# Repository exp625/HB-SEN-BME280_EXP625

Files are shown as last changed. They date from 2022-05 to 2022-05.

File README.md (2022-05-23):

# HB-SEN-BME280_EXP625

**PCB for DIY AsksinPP++ Temperature/Humidity/Pressure sensor based on a BOSCH BME280 sensor and an Arduino Pro Mini**

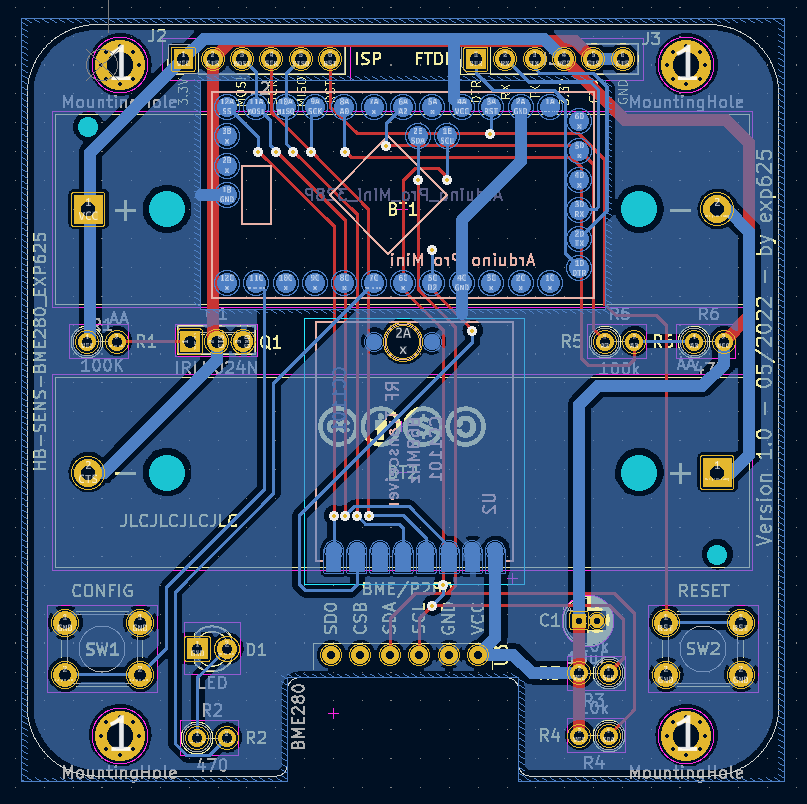
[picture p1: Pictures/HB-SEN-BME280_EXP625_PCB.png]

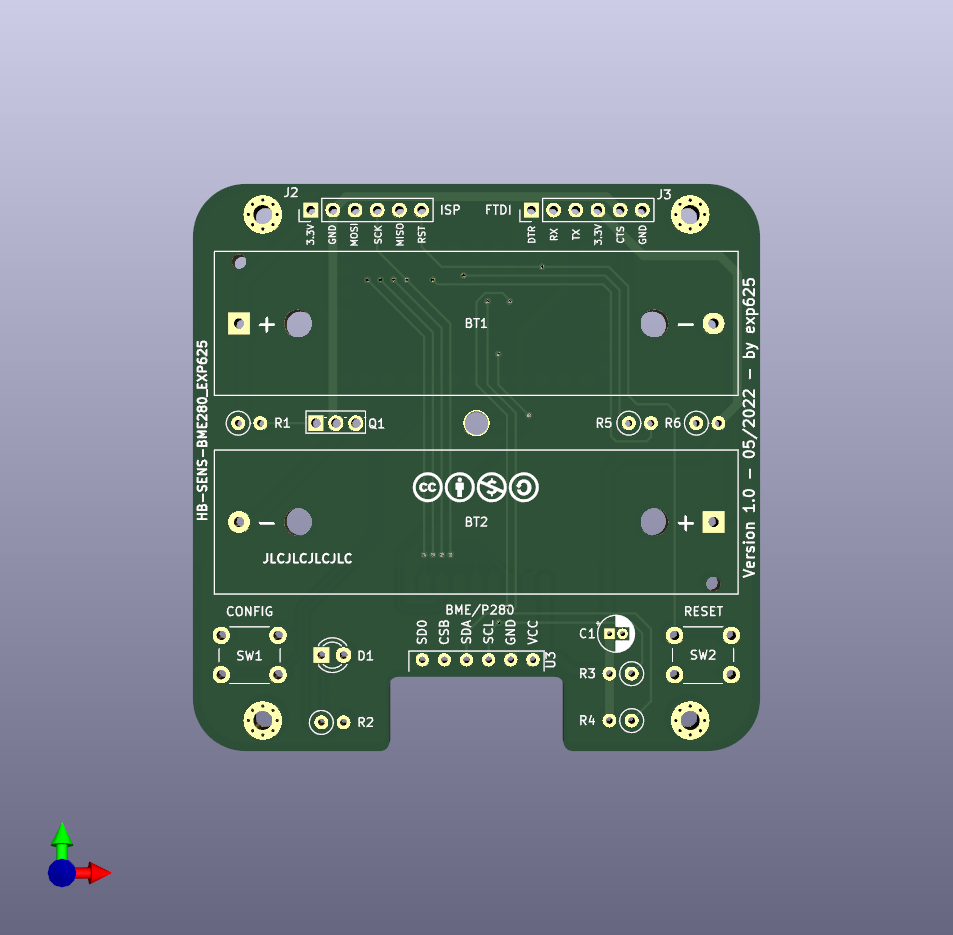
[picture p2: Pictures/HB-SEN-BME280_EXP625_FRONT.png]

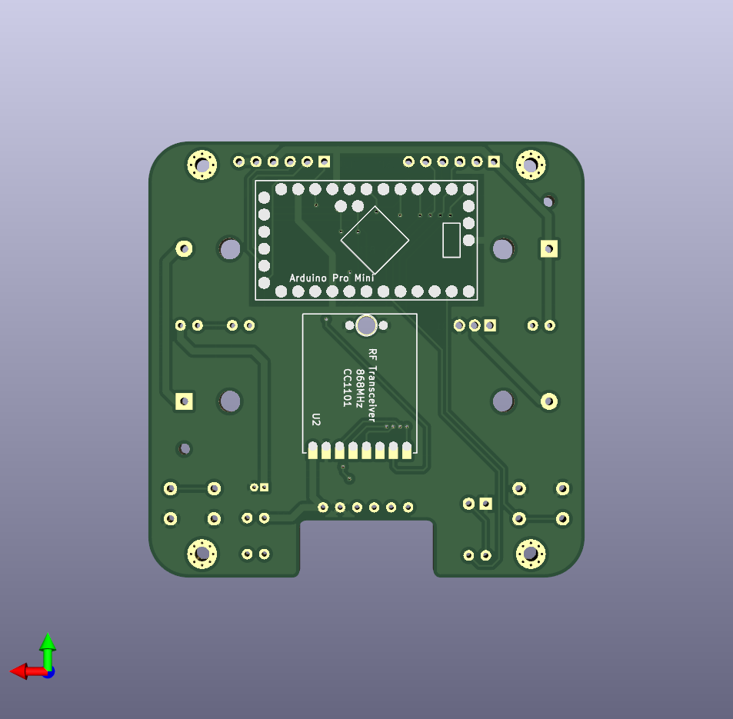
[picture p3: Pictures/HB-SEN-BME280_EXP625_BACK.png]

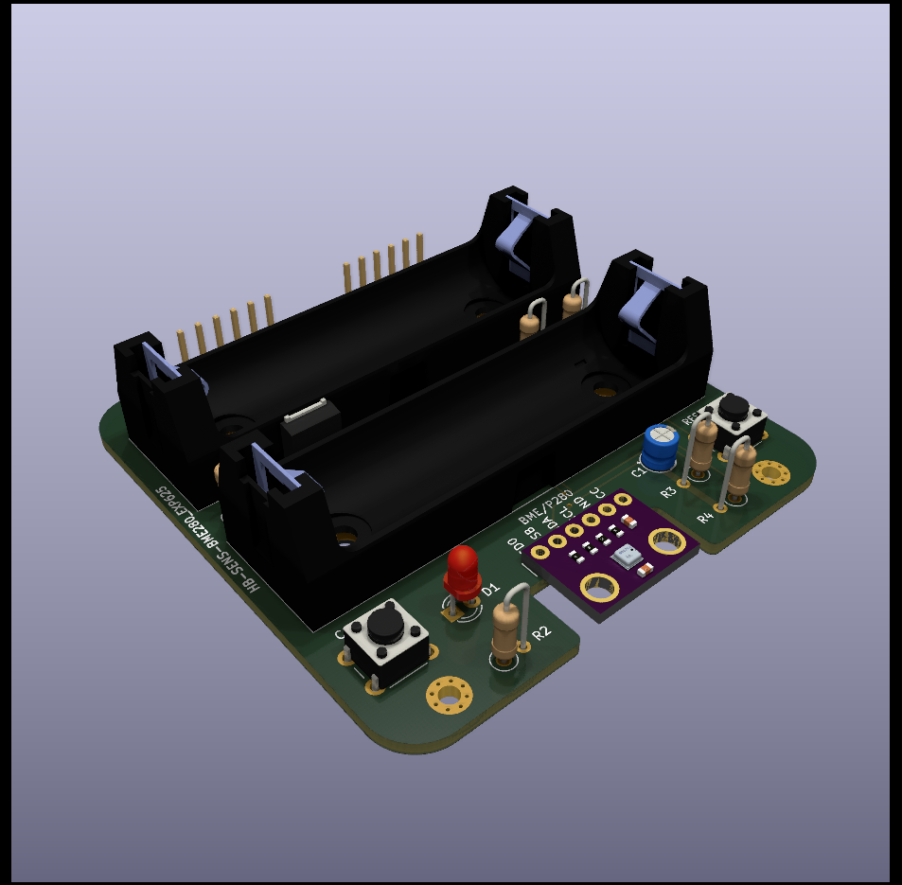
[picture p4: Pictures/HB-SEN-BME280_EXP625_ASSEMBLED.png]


## Credits

- This PCB is derived from FUEL4LP's PCB [HB-UNI-SEN-BATT_FUEL4EP](https://github.com/FUEL4EP/HomeAutomation/tree/master/AsksinPP_developments/PCBs/HB-UNI-SEN-BATT_FUEL4EP) and [HB-UNI-SEN-BATT_ATMega1284P_E07-868MS10_FRAM_FUEL4EP ](https://github.com/FUEL4EP/HomeAutomation/tree/master/AsksinPP_developments/PCBs/HB-UNI-SEN-BATT_ATMega1284P_E07-868MS10_FRAM_FUEL4EP).

## Changes

- Smaller PCB footprint to fit into the CBRS02VWH case
- surface mount assembly of the arduino and c1101 module to save space
- specific to one bme280 chip, everything else removed
- additional reset button, because the onboard reset button of the arduino needs to be removed due to the height.

## Hands-on test

The provided gerber files were used to order the pcb from JLCPCB and assemble 4 sensors, which are working perfectly for some time now

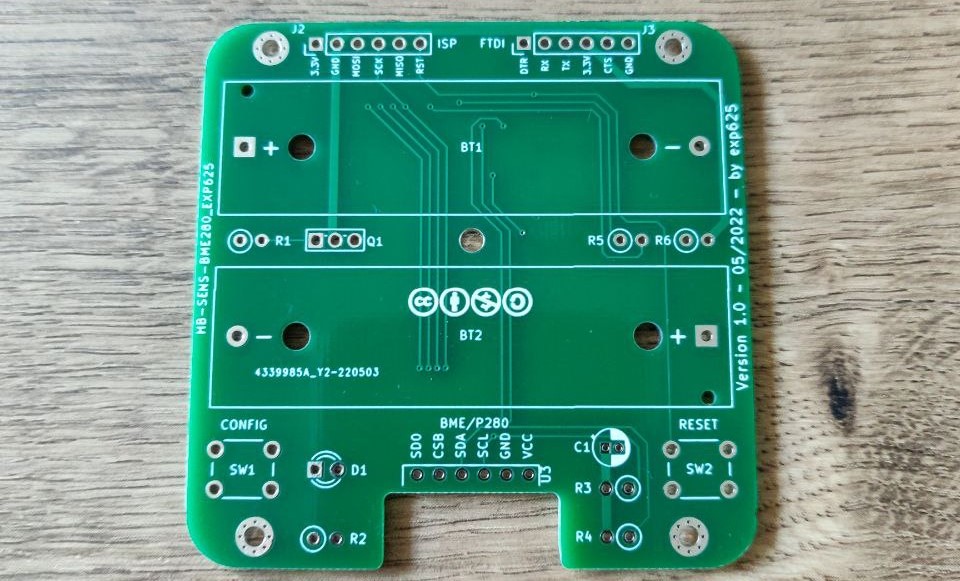
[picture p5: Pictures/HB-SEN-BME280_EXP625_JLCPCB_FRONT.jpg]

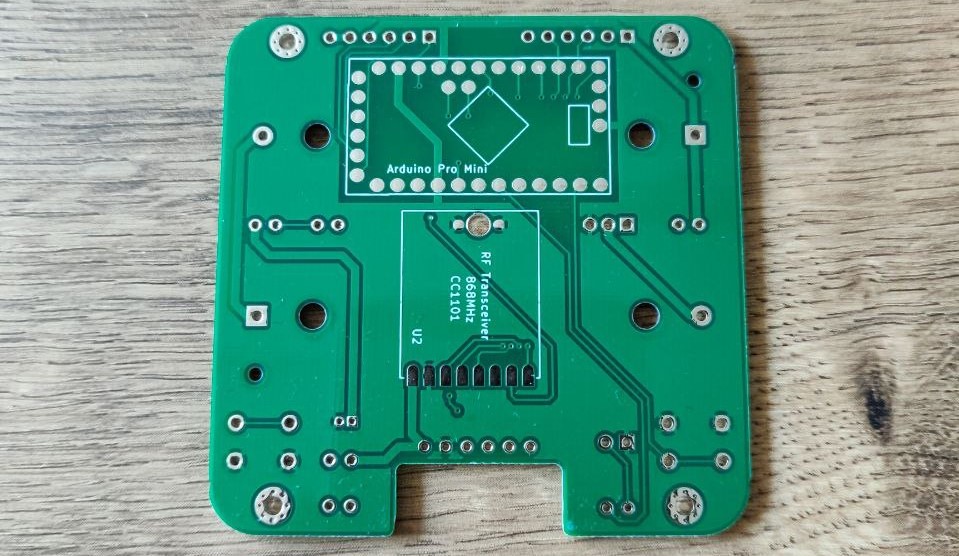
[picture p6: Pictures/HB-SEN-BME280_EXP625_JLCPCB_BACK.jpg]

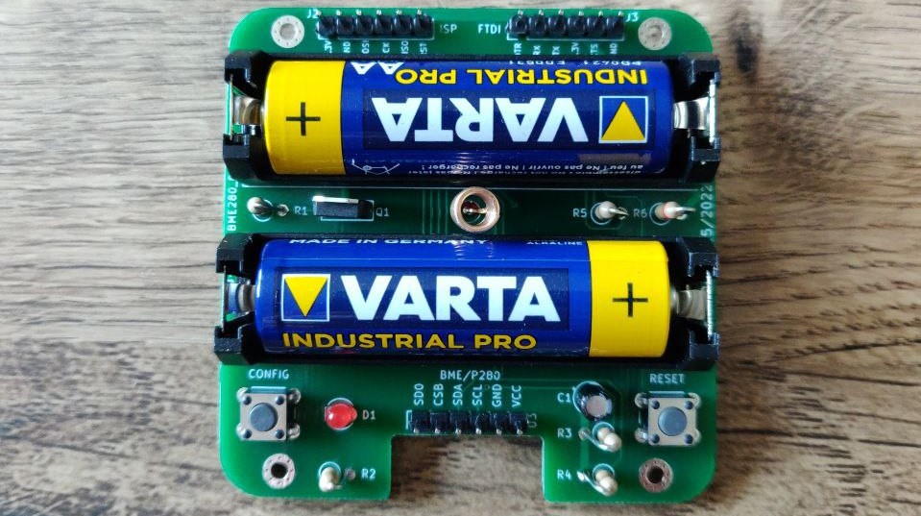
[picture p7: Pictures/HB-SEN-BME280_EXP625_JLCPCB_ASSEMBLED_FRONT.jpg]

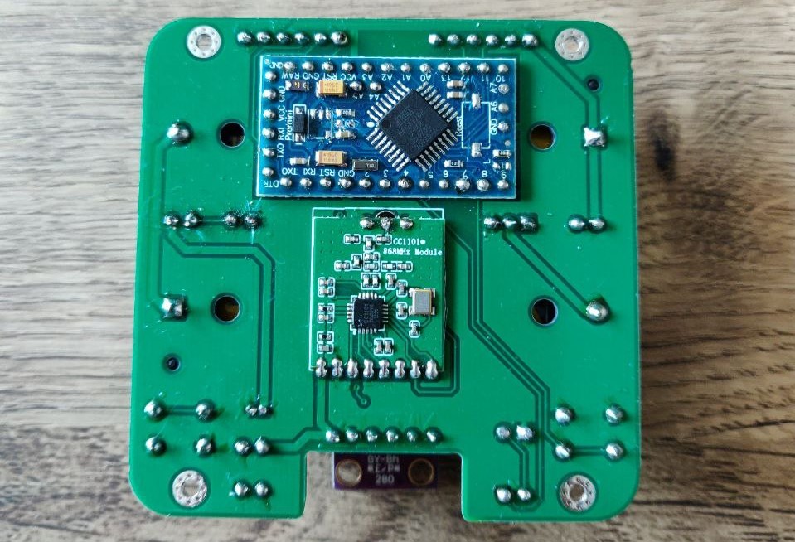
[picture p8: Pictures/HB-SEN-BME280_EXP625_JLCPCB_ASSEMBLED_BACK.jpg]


## Part List

| Count | Part | Label |
|---|---|---|
| 1 | IRLU024N | Q1 |
| 2 | Resistor 100 kOhm | R1,R5 |
| 1 | Resistor 470 Ohm | R2 |
| 2 | Resistor 10 kOhm | R3,R4 |
| 1 | Resistor 220 kOhm | R6 |
| 1 | 10uF RM 1.5 | C1 |
| 3 | 6 Pin Jumper 2.54mm  | J1, J2, J3 |
| 2 | Battery Holder 6S-AA | BT1, BT2 |
| 1 | Arduino Pro Mini | U1 |
| 1 | C1101 RF Module | U2 |
| 1 | BME280 3.3V Devboard | U3 |
| 1 | Red 3mm LED | D1 |
| 2 | Button 6x6mm | SW1,SW2 |

Remove onboard leds, button and voltage regulator from the arduino board.

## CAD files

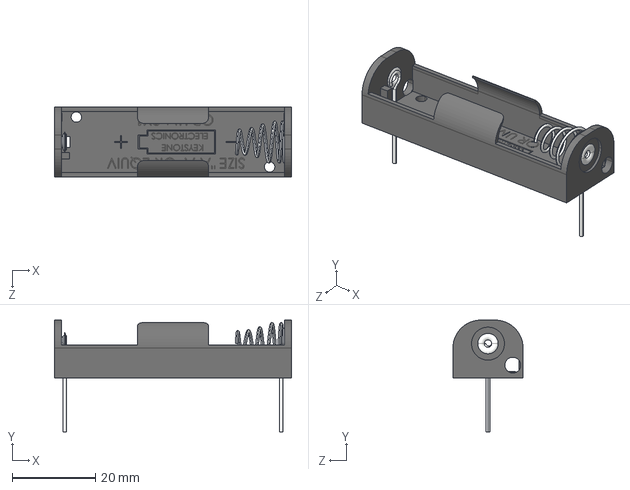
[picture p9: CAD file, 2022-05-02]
3D_Models/KEYSTONE 2460.step
57.0 x 26.9 x 16.9 mm

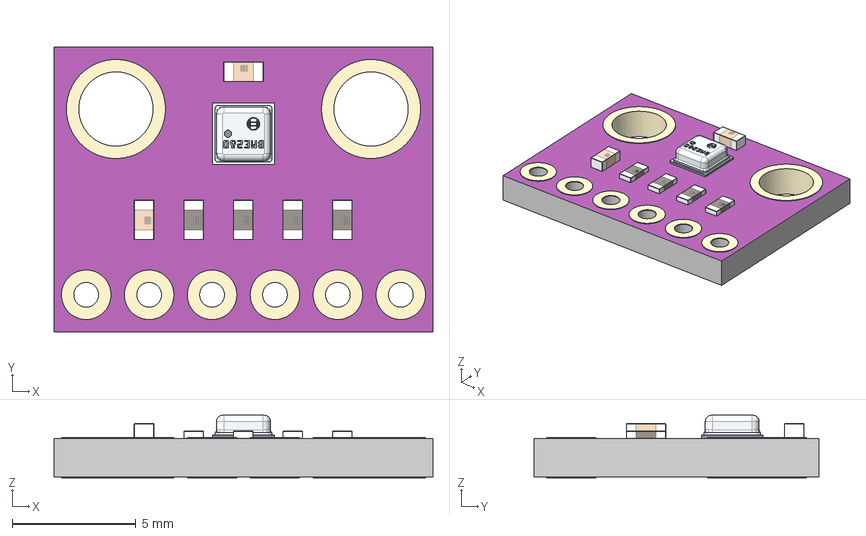
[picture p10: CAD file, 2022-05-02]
3D_Models/bme280.step
15.3 x 11.5 x 2.52 mm
Komponente1
Komponente2
Komponente3
Komponente4
Komponente5
Komponente6
Komponente7
Komponente8
Beschriftung
C0603 x 2
R0603 x 4
BME280

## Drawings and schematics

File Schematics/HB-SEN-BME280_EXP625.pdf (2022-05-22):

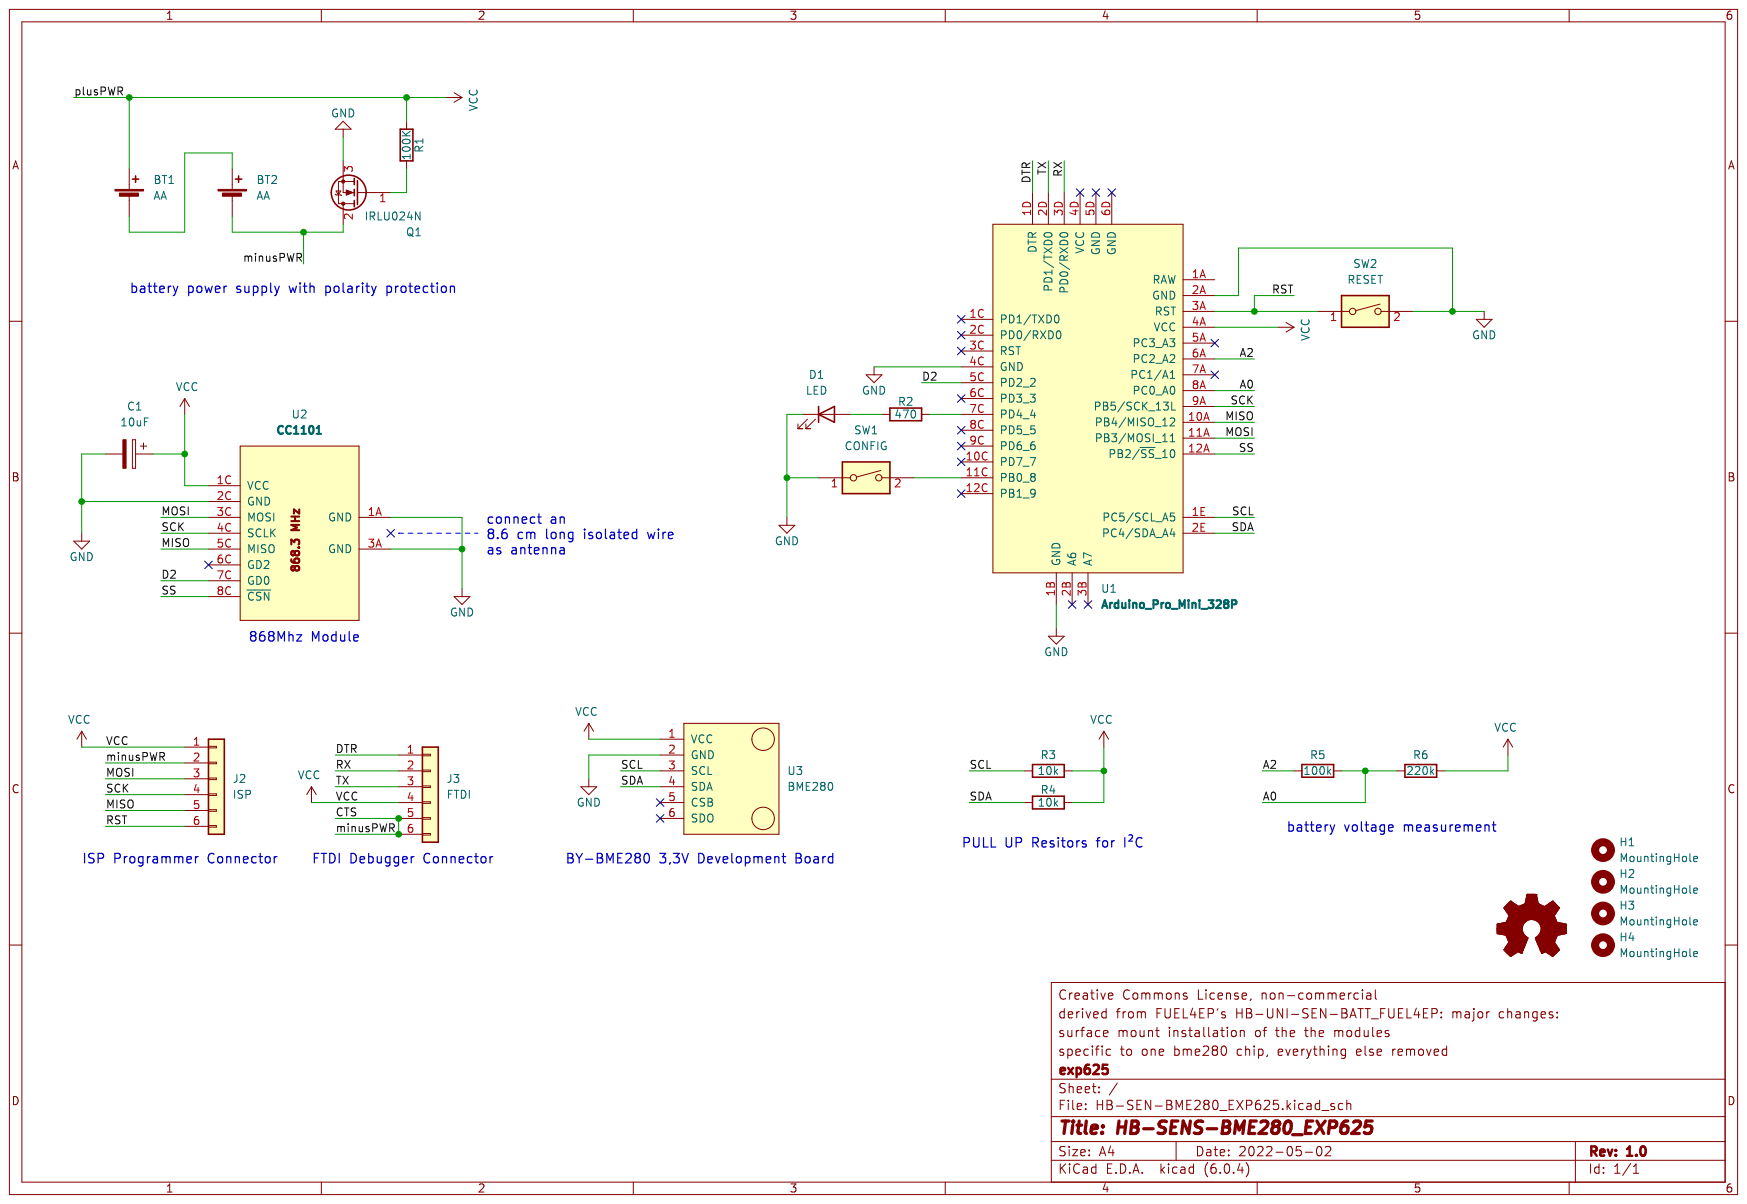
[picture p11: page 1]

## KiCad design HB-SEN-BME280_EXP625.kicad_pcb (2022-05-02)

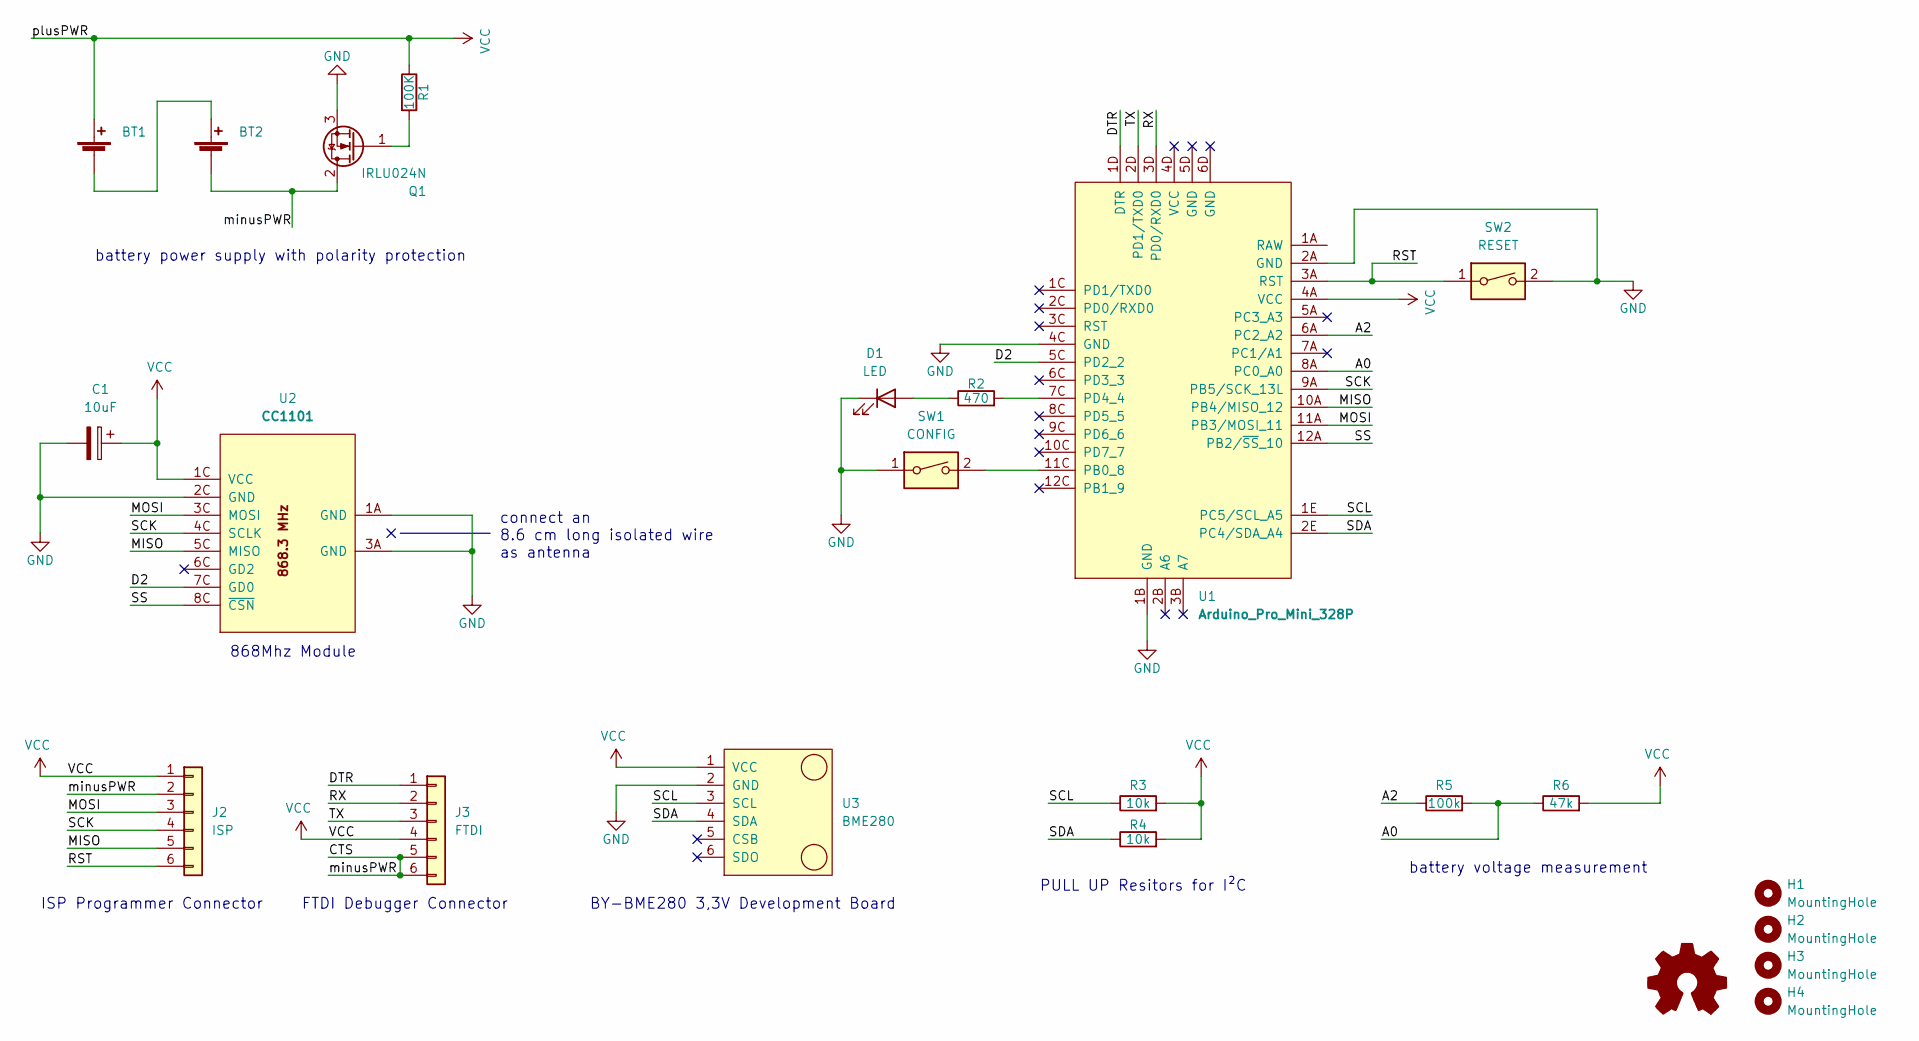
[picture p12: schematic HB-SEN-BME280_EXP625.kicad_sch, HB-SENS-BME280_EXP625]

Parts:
BT1, BT2: (no value)
C1: 10uF; CP_Radial_D4.0mm_P1.50mm
D1: LED; LED_D3.0mm
H1, H2, H3, H4: MountingHole; MountingHole_2.2mm_M2_Pad_Via
J2: ISP; PinHeader_1x06_P2.54mm_Vertical
J3: FTDI; PinHeader_1x06_P2.54mm_Vertical
LOGO1: Logo_Open_Hardware_Small; CC-BY-ND-SA; JLCPCB BOM 0
Q1: IRLU024N; TO-251-3_Vertical
R1: 100K; R_Axial_DIN0207_L6.3mm_D2.5mm_P2.54mm_Vertical
R2: 470; R_Axial_DIN0207_L6.3mm_D2.5mm_P2.54mm_Vertical
R3, R4: 10k; R_Axial_DIN0207_L6.3mm_D2.5mm_P2.54mm_Vertical
R5: 100k; R_Axial_DIN0207_L6.3mm_D2.5mm_P2.54mm_Vertical
R6: 47k; R_Axial_DIN0207_L6.3mm_D2.5mm_P2.54mm_Vertical
SW1: CONFIG; SW_PUSH_6mm_H5mm
SW2: RESET; SW_PUSH_6mm_H5mm
U1: Arduino_Pro_Mini_328P; ArduinoProMini
U2: CC1101
U3: BME280; module_bme280

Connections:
/A0: R5.2, R6.1, U1.8A (PC0_A0)
/A2: R5.1, U1.6A (PC2_A2)
/CTS: BT2.2 (-), J2.2, J3.5, J3.6, Q1.2 (D)
/D2: U1.5C (PD2_2), U2.7C (GD0)
/DTR: J3.1, U1.1D (DTR)
/MISO: J2.5, U1.10A (PB4/MISO_12), U2.5C (MISO)
/MOSI: J2.3, U1.11A (PB3/MOSI_11), U2.3C (MOSI)
/RST: J2.6, SW2.1, U1.3A (RST)
/RX: J3.2, U1.3D (PD0/RXD0)
/SCK: J2.4, U1.9A (PB5/SCK_13L), U2.4C (SCLK)
/SCL: R3.1, U1.1E (PC5/SCL_A5), U3.3 (SCL)
/SDA: R4.1, U1.2E (PC4/SDA_A4), U3.4 (SDA)
/SS: U1.12A (PB2/~SS_10), U2.8C (~CSN)
/TX: J3.3, U1.2D (PD1/TXD0)
GND: C1.2, D1.1 (K), Q1.3 (S), SW1.1, SW2.2, U1.1B (GND), U1.2A (GND), U1.4C (GND), U2.1A (GND), U2.2C (GND), U2.3A (GND), U3.2 (GND)
unnamed: BT1.2 (-), BT2.1 (+)
unnamed: D1.2 (A), R2.1
unnamed: Q1.1 (G), R1.2
unnamed: R2.2, U1.7C (PD4_4)
unnamed: SW1.2, U1.11C (PB0_8)
VCC: BT1.1 (+), C1.1, J2.1, J3.4, R1.1, R3.2, R4.2, R6.2, U1.4A (VCC), U2.1C (VCC), U3.1 (VCC)

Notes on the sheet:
connect an 8.6 cm long isolated wire as antenna
battery power supply with polarity protection
BY-BME280 3,3V Development Board
PULL UP Resitors for I²C
battery voltage measurement
FTDI Debugger Connector
ISP Programmer Connector
868Mhz Module

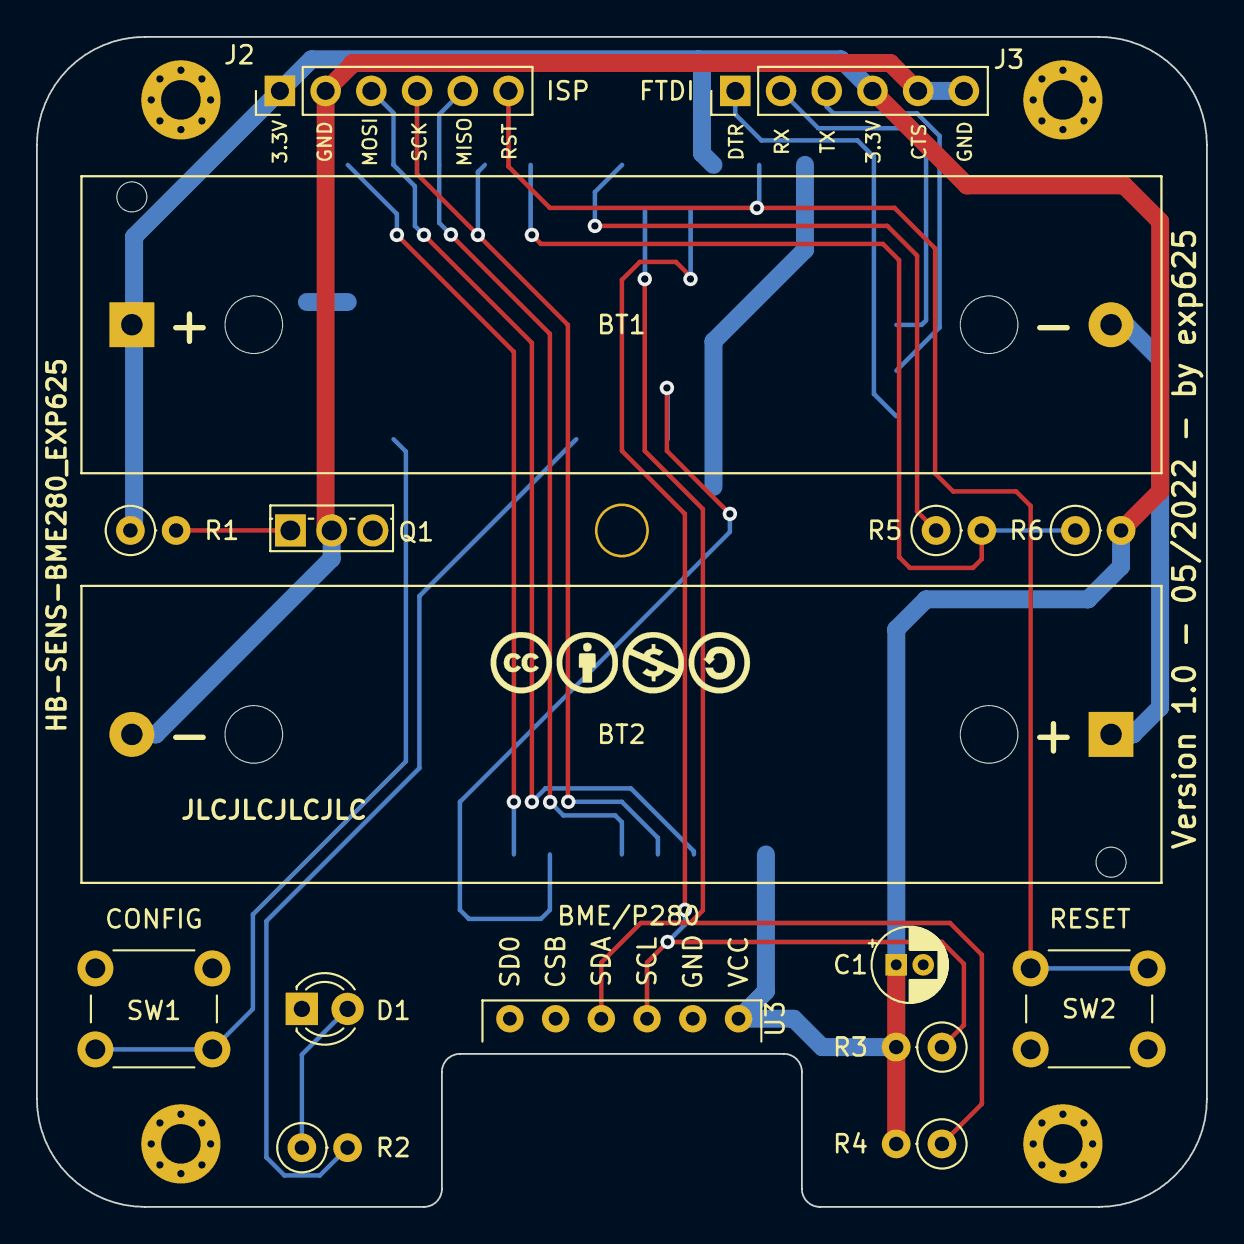
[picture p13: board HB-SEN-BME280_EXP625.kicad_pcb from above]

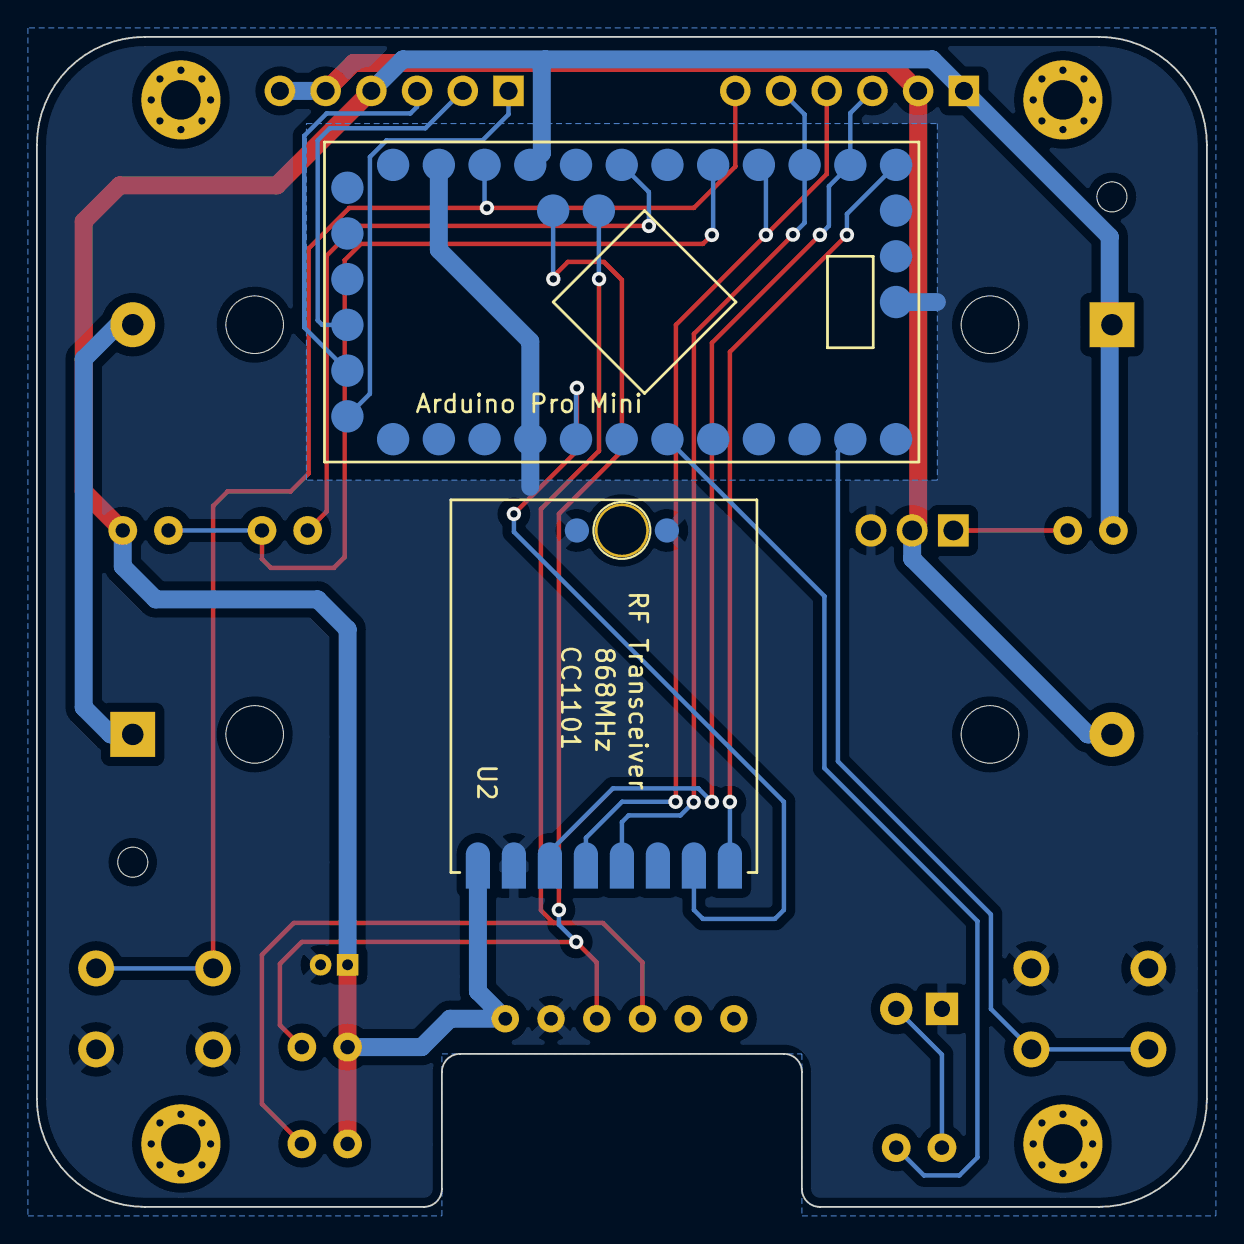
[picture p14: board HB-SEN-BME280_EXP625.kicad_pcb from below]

Board: 2 copper layers, 65.0 x 65.0 mm, 23 parts (2 on the bottom side), 21 nets.

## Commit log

2022-05-02 :sparkles: Revision 1.0
    :sparkles: Revision 1.0 with Keystone 2460 / Goobay AA battery holder
    :sparkles: Revision 1.0
    [HB-SEN-BME280_EXP625-B_Cu.gbr, HB-SEN-BME280_EXP625-B_Mask.gbr, HB-SEN-BME280_EXP625-B_Paste.gbr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]
2022-05-22 :bug: Fix resistor value in voltage divider
    [HB-SEN-BME280_EXP625.kicad_sch]

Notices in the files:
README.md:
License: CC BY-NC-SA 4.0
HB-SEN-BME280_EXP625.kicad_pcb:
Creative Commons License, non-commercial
